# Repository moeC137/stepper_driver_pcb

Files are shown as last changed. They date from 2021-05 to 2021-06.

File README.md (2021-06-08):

# stepper_driver_pcb

Video series:
https://www.youtube.com/playlist?list=PL1WGC6yQh6iIVykta8OX8R-CPlR6SFzXf

3D print files:
https://www.thingiverse.com/thing:4840651

Stepper driver board for a EDM Z-Axis in Kicad
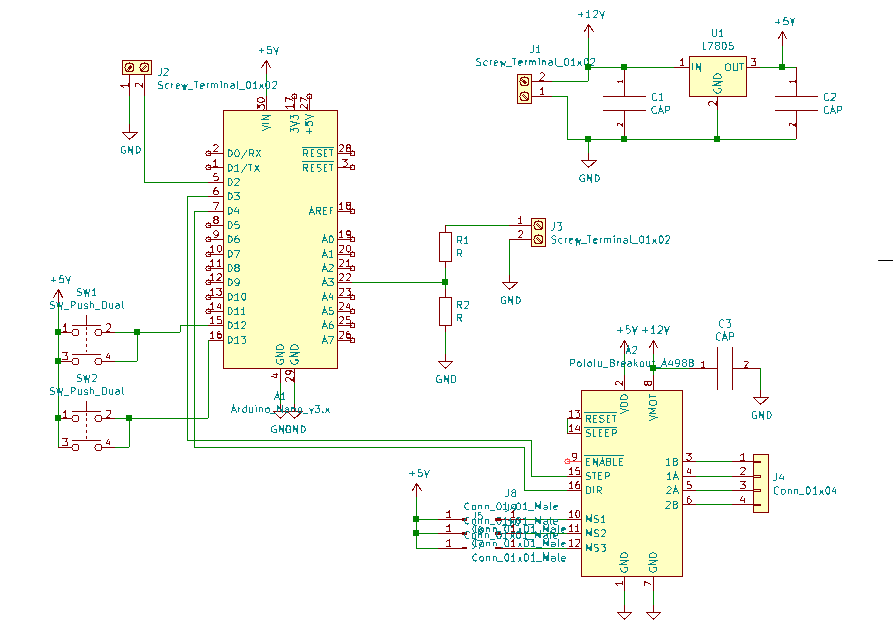
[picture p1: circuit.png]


PCB Layout
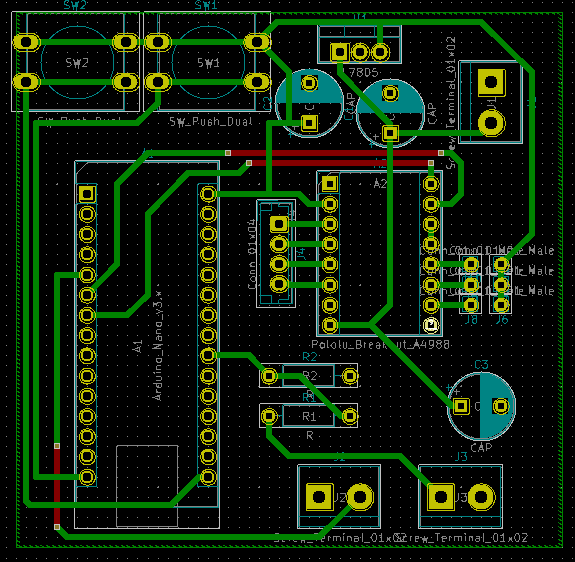
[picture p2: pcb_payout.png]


Using a Current controlled lab power supply as trigger for retraction
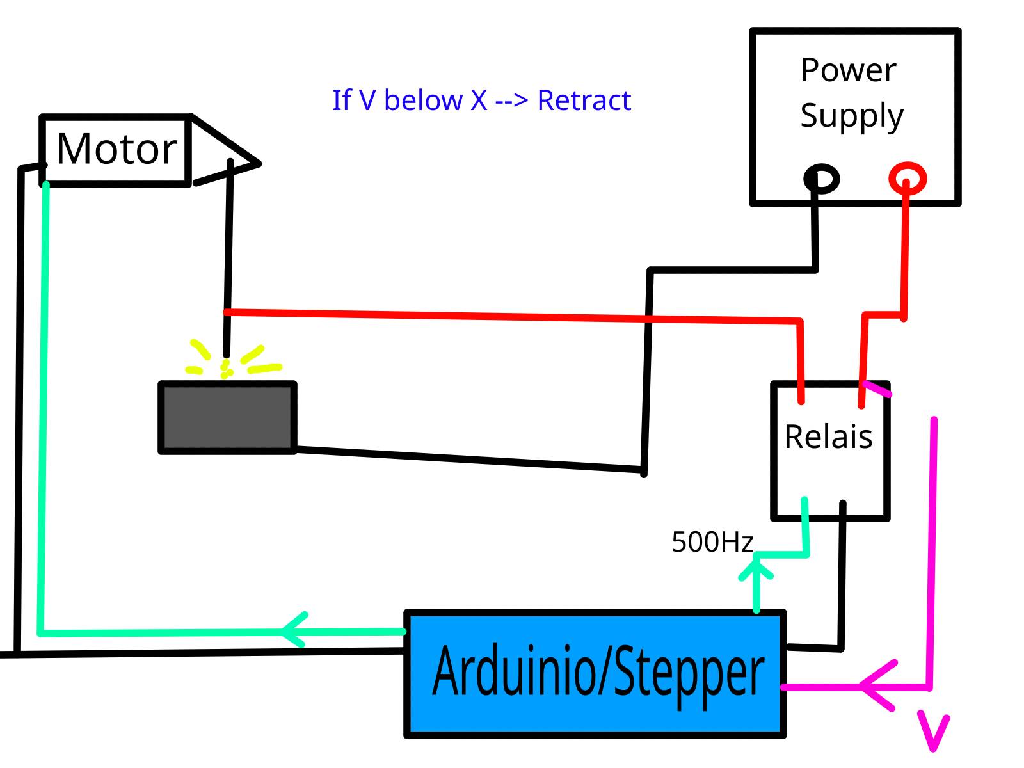
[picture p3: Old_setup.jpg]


Using a Shunt to trigger Retraction
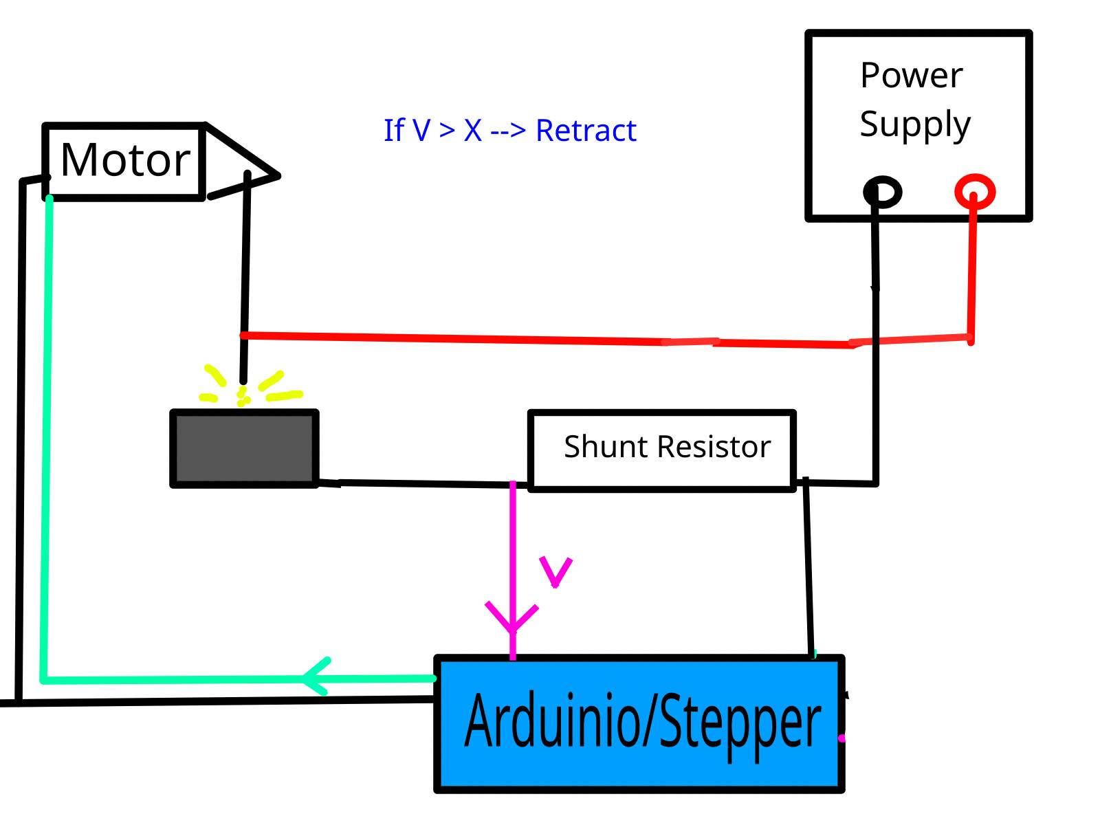
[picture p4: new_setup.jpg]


Shunt + hf Pulsed Source
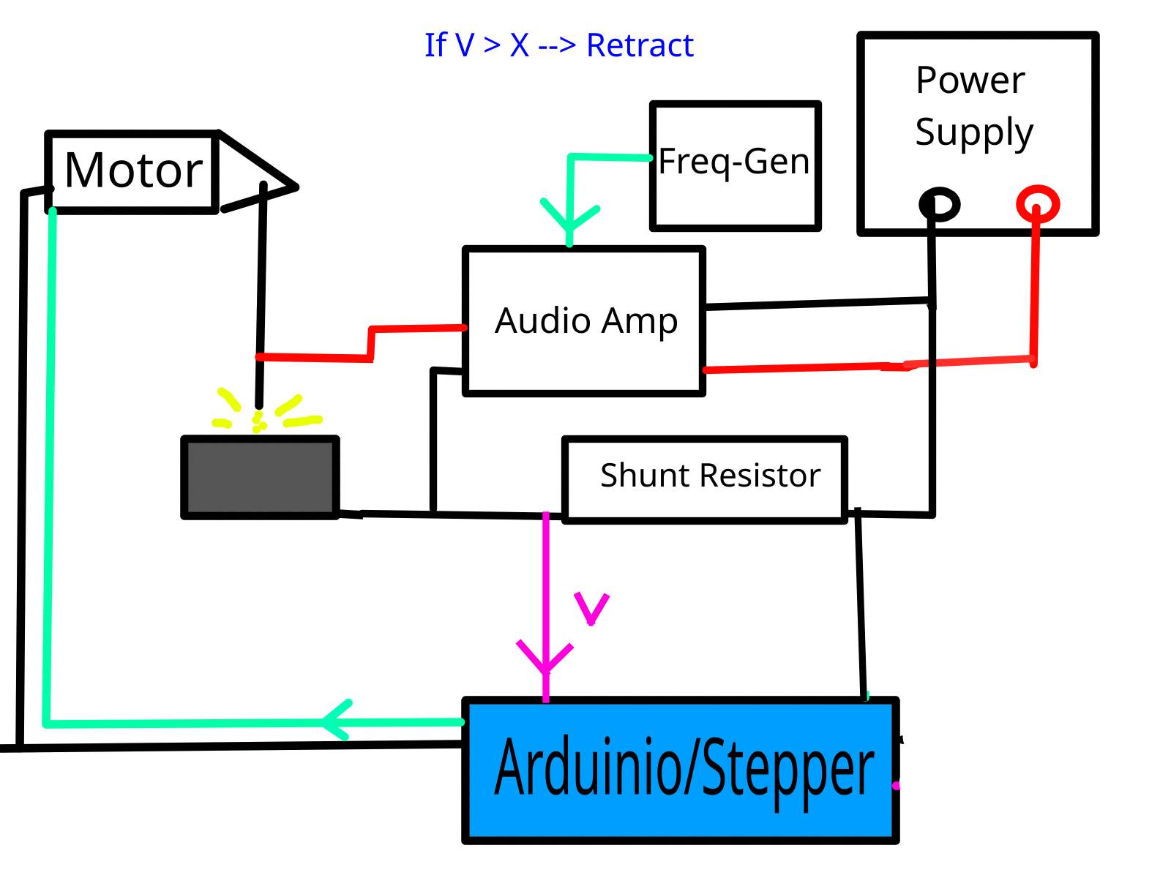
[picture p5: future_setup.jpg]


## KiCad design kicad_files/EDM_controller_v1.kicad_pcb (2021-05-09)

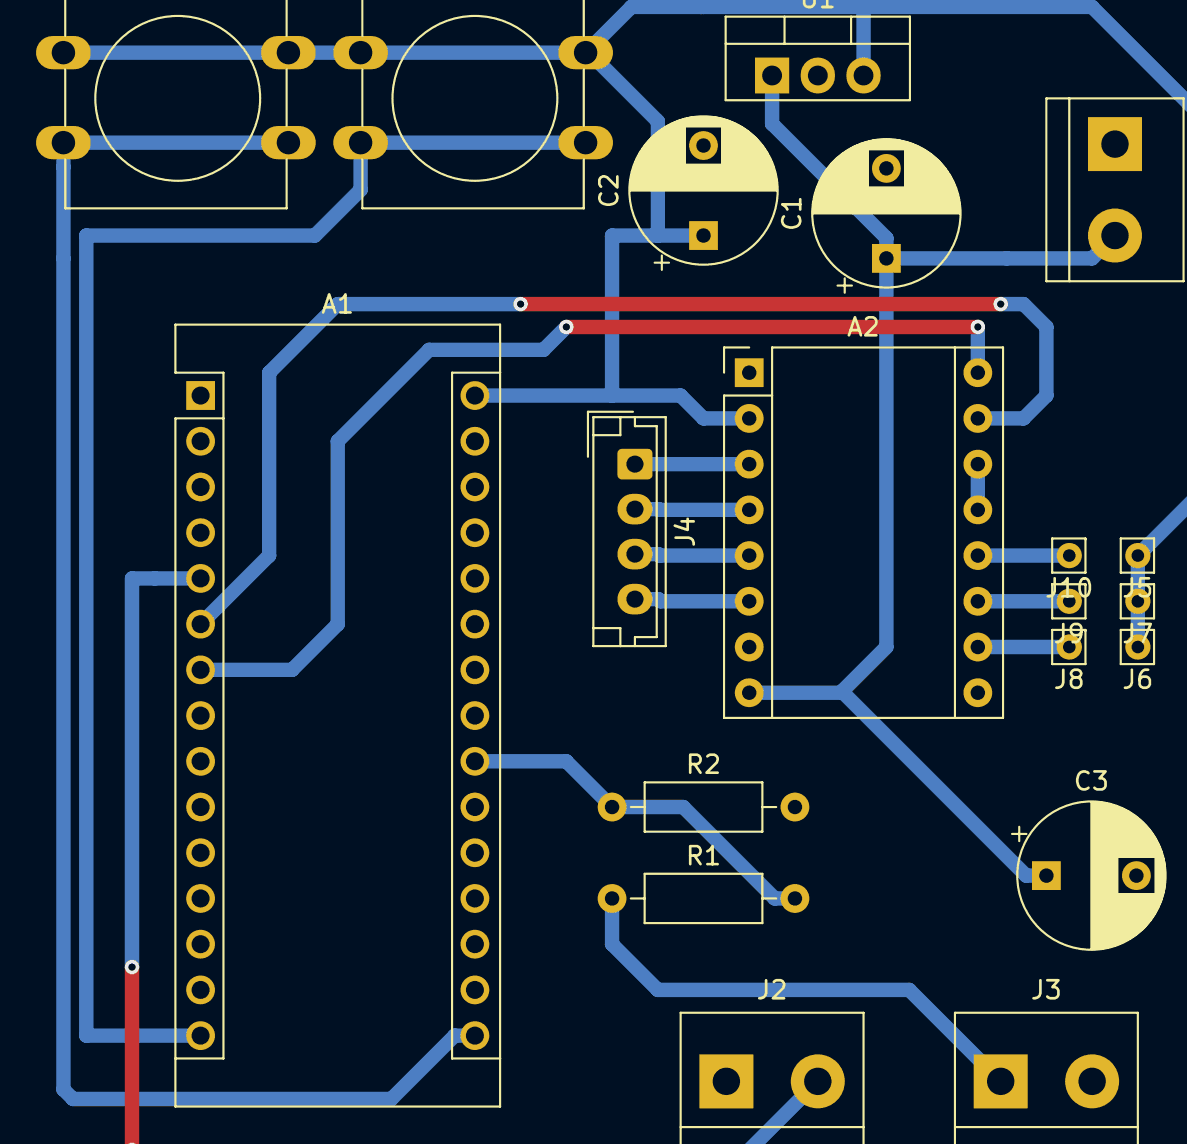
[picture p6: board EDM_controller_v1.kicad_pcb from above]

Board: 2 copper layers, 20 parts (0 on the bottom side), 18 nets.

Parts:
A1: Arduino_Nano_v3.x; Arduino_Nano
A2: Pololu_Breakout_A4988; Pololu_Breakout-16_15.2x20.3mm
C1, C2, C3: CAP; CP_Radial_D8.0mm_P5.00mm
J1, J2, J3: Screw_Terminal_01x02; TerminalBlock_bornier-2_P5.08mm
J4: Conn_01x04; JST_EH_B4B-EH-A_1x04_P2.50mm_Vertical
J5, J6, J7, J8, J9, J10: Conn_01x01_Male; Pin_D0.7mm_L6.5mm_W1.8mm_FlatFork
R1, R2: R; R_Axial_DIN0207_L6.3mm_D2.5mm_P10.16mm_Horizontal
SW1, SW2: SW_Push_Dual; SW_PUSH-12mm
U1: L7805; TO-220-3_Vertical

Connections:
+5V: A1.30, A2.2, C2.1, J5.1, J6.1, J7.1, SW1.1, SW2.1, U1.3
+12V: A2.8, C1.1, C3.1, J1.2, U1.1
GND: A1.4, A1.29, A2.1, A2.7, C1.2, C2.2, C3.2, J1.1, J2.1, J3.2, R2.2, U1.2
unnamed: A1.5, J2.2
unnamed: A1.6, A2.15
unnamed: A1.7, A2.16
unnamed: A1.15, SW1.2
unnamed: A1.16, SW2.2
unnamed: A1.22, R1.2, R2.1
unnamed: A2.3, J4.1
unnamed: A2.4, J4.2
unnamed: A2.5, J4.3
unnamed: A2.6, J4.4
unnamed: A2.10, J8.1
unnamed: A2.11, J9.1
unnamed: A2.12, J10.1
unnamed: A2.13, A2.14
unnamed: J3.1, R1.1

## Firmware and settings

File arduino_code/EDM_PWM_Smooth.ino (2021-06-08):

const int stepPin = 3; 
const int dirPin = 4; 
const int toggleA = 12;
const int toggleB = 13;
//const int probe= 2;
const int relai = 2;
const int sensor = A3;
int buttonStateA = 0; 
int buttonStateB = 0; 
int probeState = 0; 
int sensorValue = 0;


//Parameters
const int aisPin  = A3;
const int numReadings  = 20;
int readings [numReadings];
int readIndex  = 0;
long total  = 0;


//Variables
int aisVal  = 0;


void setup() {
  // Sets int / outputs
  pinMode(stepPin,OUTPUT); 
  pinMode(dirPin,OUTPUT);
  pinMode(toggleA,INPUT);
  pinMode(toggleB,INPUT);
  //pinMode(probe,INPUT_PULLUP);
  pinMode(relai, OUTPUT);
  pinMode(sensor,INPUT);
  Serial.begin(9600);


  //Init Serial USB
  
  Serial.println(F("Initialize System"));
  //Init AnalogSmooth
  pinMode(aisPin, INPUT);


  
}
void loop() {
  buttonStateA = digitalRead(toggleA);
  buttonStateB = digitalRead(toggleB);
  //probeState = digitalRead(probe);
  if (buttonStateA == HIGH) {
  
    digitalWrite(dirPin,LOW); // Enables the motor to move in a particular direction
    // Makes 200 pulses for making one full cycle rotation
      for(int x = 0; x < 50;  x++) {
      digitalWrite(stepPin,HIGH); 
      delayMicroseconds(500); 
      digitalWrite(stepPin,LOW); 
      delayMicroseconds(500); 
      }
    
  }
  else {
    digitalWrite(stepPin,LOW);
  }

if (buttonStateB == HIGH) {
 digitalWrite(dirPin,HIGH); // Enables the motor to move in a particular direction
  // Makes 200 pulses for making one full cycle rotation
  for(int x = 0; x < 50; x++) {
    digitalWrite(stepPin,HIGH); 
    delayMicroseconds(500); 
    digitalWrite(stepPin,LOW); 
    delayMicroseconds(500); 
  }
  }

  else {
    digitalWrite(stepPin,LOW);
  }
  

//digitalWrite(relai, HIGH);   // turn the relai on (HIGH is the m_amper level)
/////////////////////////////////////////////////////////////////////////////
//digitalWrite(relai, HIGH);   // turn the relai on (HIGH is the m_amper level)

  readAnalogSmooth();
  //Serial.print(F("ais avg : ")); Serial.println(smooth());
  //delay(200);



//sensorValue = smooth();//analogRead(sensor);
long m_amper = smooth();//map(sensorValue,0,77,0,3000); //* (5.0 / 1023.0)*55;

Serial.println(m_amper);


//digitalWrite(relai, LOW);    // turn the relai off by making the m_amper LOW
if (m_amper < 10) {
for(int x = 0; x < 1;  x++) {
digitalWrite(dirPin,LOW); // Enables the motor to move in a particular direction
//digitalWrite(relai, HIGH);   // turn the relai on (HIGH is the m_amper level)
digitalWrite(stepPin,HIGH); 
delay(1); 
digitalWrite(stepPin,LOW); 
delay(1); 

//digitalWrite(relai, LOW);    // turn the relai off by making the m_amper LOW
delay(1);
}
}
else {}

//sensorValue = analogRead(sensor);
//float m_amper = sensorValue * (5.0 / 1023.0)*55;
//digitalWrite(relai, LOW);    // turn the relai off by making the m_amper LOW
if (m_amper > 20) {
for(int x = 0; x < 1;  x++) {
digitalWrite(dirPin,HIGH); // Enables the motor to move in a particular direction
//digitalWrite(relai, HIGH);   // turn the relai on (HIGH is the m_amper level)
digitalWrite(stepPin,HIGH); 
delay(1); 
digitalWrite(stepPin,LOW); 
delay(1); 

//digitalWrite(relai, LOW);    // turn the relai off by making the m_amper LOW
delay(1); 
  }
}
else {}     

/////////////////////////////////////////////////////////////////////////////
//digitalWrite(relai, LOW);    // turn the relai off by making the m_amper LOW 


//delay(50);
}




void readAnalogSmooth( ) { /* function readAnalogSmooth */
  ////Test routine for AnalogSmooth
  aisVal = analogRead(aisPin);
  //Serial.print(F("ais val ")); Serial.println(aisVal);
}

long smooth() { /* function smooth */
  ////Perform average on sensor readings
  long average;
  // subtract the last reading:
  total = total - readings[readIndex];
  // read the sensor:
  readings[readIndex] = analogRead(aisPin);
  // add value to total:
  total = total + readings[readIndex];
  // handle index
  readIndex = readIndex + 1;
  if (readIndex >= numReadings) {
    readIndex = 0;
  }
  // calculate the average:
  average = total / numReadings;

  return average;
}


/////////////////////////////////////////////////////////
/*
   digitalWrite(dirPin,LOW); // Enables the motor to move in a particular direction
    // Makes 200 pulses for making one full cycle rotation
    for(int x = 0; x < 30;  x++) {
      digitalWrite(relai, HIGH);   // turn the relai on (HIGH is the m_amper level)
      sensorValue = analogRead(sensor);
    // print out the value you read:
    float m_amper = sensorValue * (5.0 / 1023.0)*55;
    Serial.println(m_amper);
    //Serial.println(sensorValue);
      digitalWrite(stepPin,HIGH); 
      delay(1); 
      digitalWrite(stepPin,LOW); 
      delay(1); 
      
      digitalWrite(relai, LOW);    // turn the relai off by making the m_amper LOW
      delay(20);
      }
      
  

  digitalWrite(dirPin,HIGH); // Enables the motor to move in a particular direction
  // Makes 200 pulses for making one full cycle rotation
  for(int x = 0; x < 29; x++) {
    digitalWrite(relai, HIGH);   // turn the relai on (HIGH is the m_amper level)
    sensorValue = analogRead(sensor);
    // print out the value you read:
    float m_amper = sensorValue * (5.0 / 1023.0)*55;
    Serial.println(m_amper);
    //Serial.println(sensorValue);
    digitalWrite(stepPin,HIGH);
    delay(1); 
    digitalWrite(stepPin,LOW);
    delay(1); 
    
    digitalWrite(relai, LOW);    // turn the relai off by making the m_amper LOW
    delay(20);
  }
*/
